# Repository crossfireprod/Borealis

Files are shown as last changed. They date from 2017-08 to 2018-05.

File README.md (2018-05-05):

Borealis
==================

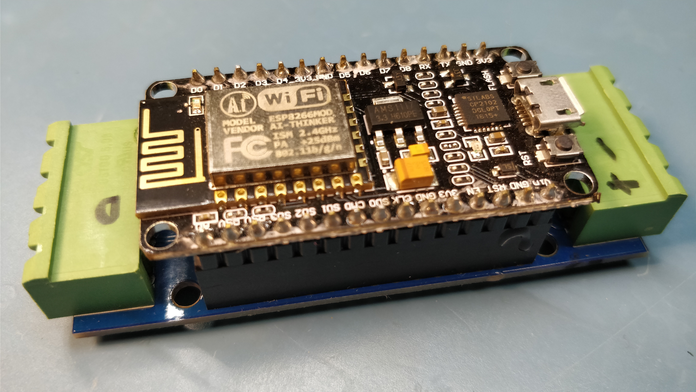
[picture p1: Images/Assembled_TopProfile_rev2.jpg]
Borealis Assembled - Top Profile
  

WS2812/DMX Light Controller For the [ESPixelStick Firmware](https://github.com/forkineye/ESPixelStick) by Shelby Merrick (forkineye).  Hardware supports both DMX (RS-485) and Pixel (WS2811/WS2812) output modes.

**Key Features**
* The [NodeMCU](https://en.wikipedia.org/wiki/NodeMCU) DEVKIT 1.0 was chosen due to pricepoint, availability, form factor, and onboard 3.3v power supply / USB interface (programmer).  
* Either a DC barrel jack or 5.08mm pluggable terminals may be used to supply power.  
* Output power and data is provided via 5.08mm pluggable terminal blocks.  
* PTC is used in lieu of a traditional fuse.  
* Drill hole in PCB allows for use of reverse firing activity LED, if desired.

Bill Of Materials
-------------------

A Bill Of Materials detailing the specific parts used in our most recent production run can be found on Octopart.  Pricing is more or less optimized around single unit quanties.

* [Pixel (WS2811/WS2812) Version](https://octopart.com/bom-tool/HFxE4Ql2)
* [DMX (RS-485) Version](https://octopart.com/bom-tool/G0dtO20q)

Note: If desired, boards can be populated for both DMX and Pixel use.  (Output mode defined by firmware configuration.)

Repository Contents
-------------------

* **/Hardware** - Eagle Schematic & PCB Layout
* **/Software** - [Platformio](http://platformio.org/) project containing [ESPixelStick Firmware](https://github.com/forkineye/ESPixelStick).
* **/Images** - Images of the schematic / PCB design, as well as a fully assembled unit.

License
-------------------

All contents of this repository are released under [Creative Commons Share-alike 4.0](http://creativecommons.org/licenses/by-sa/4.0/).

Design By: Greg Pohodich & [*ZachCross.com*](https://ZachCross.com)

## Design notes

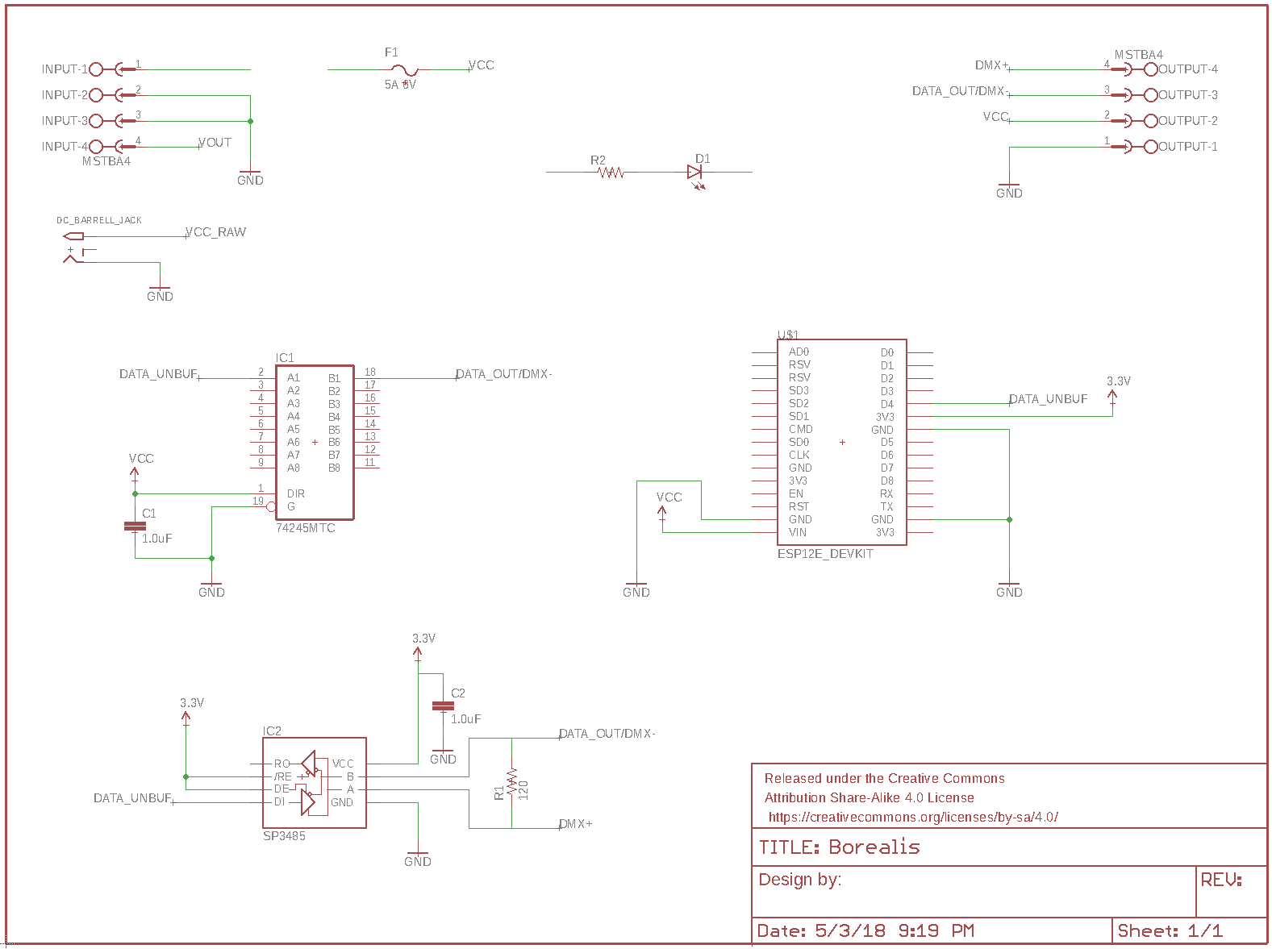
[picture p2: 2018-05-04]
Images/Schematic_Borealis_DMX&Pixel.png

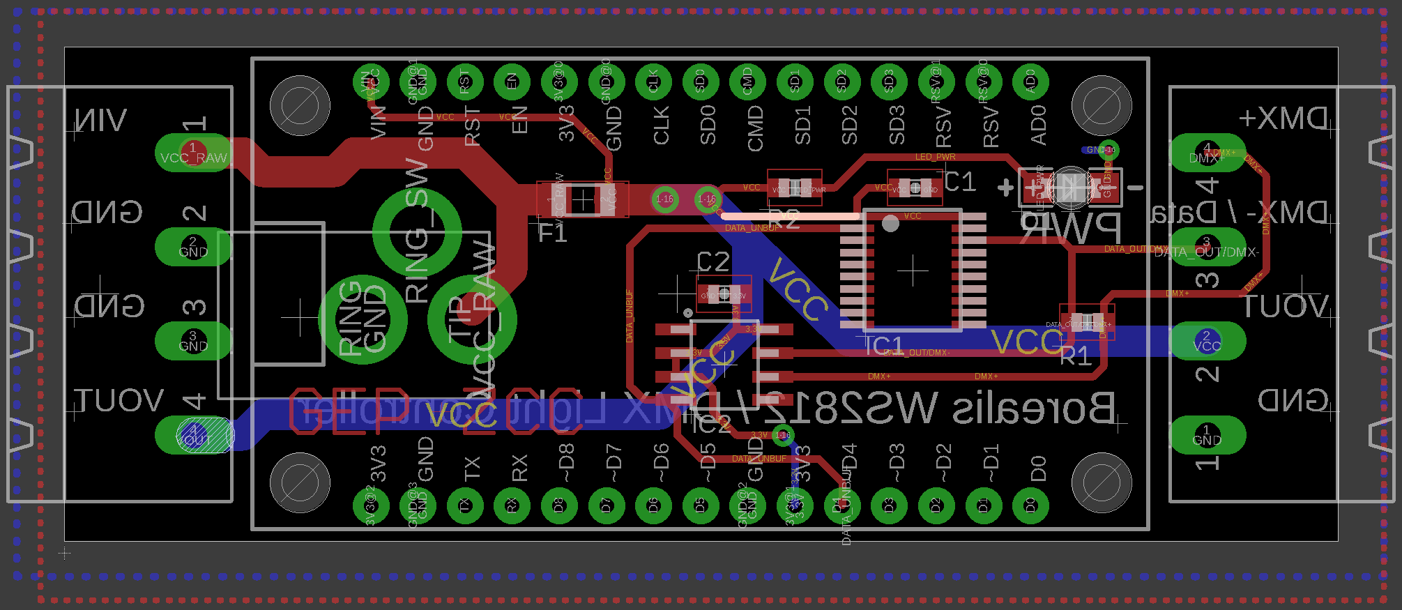
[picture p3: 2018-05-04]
Images/PCBLayout_Borealis_DMX&Pixel.png

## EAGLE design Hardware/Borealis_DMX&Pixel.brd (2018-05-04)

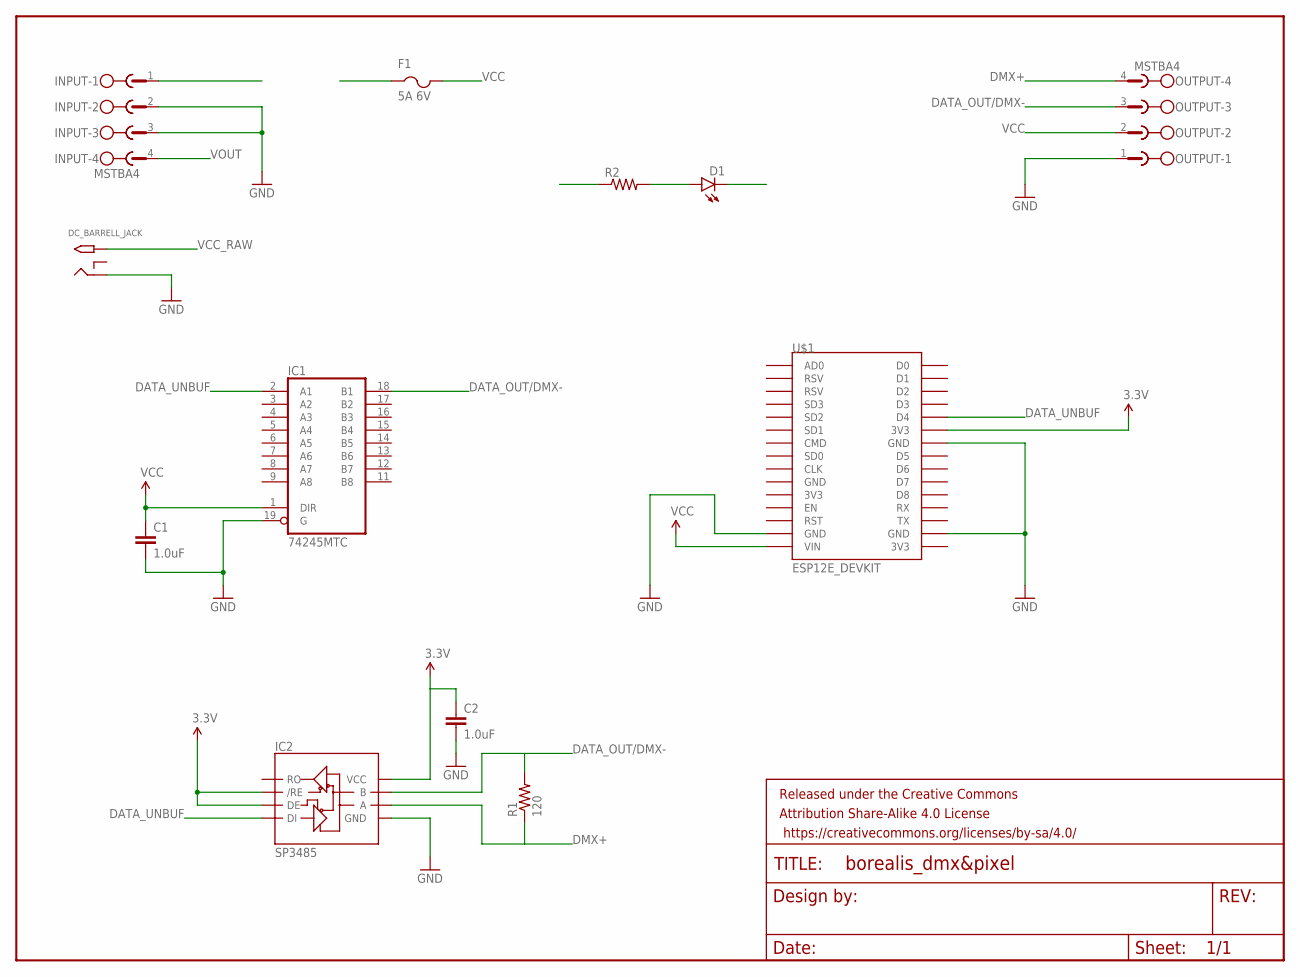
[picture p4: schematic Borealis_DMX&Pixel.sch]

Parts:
C1, C2: 1.0uF; 0603-CAP
D1: LED1206-BOTTOM; LED-1206-BOTTOM
DC_BARRELL_JACK: 2.1MMJACKTHM; PJ-102A
F1: 5A 6V; R1206
FRAME1: FRAME-LETTERNO_PACKAGE; DUMMY
IC1: 74245MTC; SSOP20
IC2: SP3485; SO08
INPUT: MSTBA4
OUTPUT: MSTBA4
R1: 120; 0603-RES
R2: RESISTOR0603-RES; 0603-RES
U$1: ESP12E_DEVKIT; DEV_LAYOUT

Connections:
3.3V: C2.1, IC2.2 (/RE), IC2.3 (DE), IC2.8 (VCC), U$1.3V3@1 (3V3)
DATA_OUT/DMX-: IC1.18 (B1), IC2.7 (B), OUTPUT.3, R1.2
DATA_UNBUF: IC1.2 (A1), IC2.4 (DI), U$1.D4
DMX+: IC2.6 (A), OUTPUT.4, R1.1
GND: C1.2, C2.2, D1.C, DC_BARRELL_JACK.RING, IC1.10 (GND), IC1.19 (G), IC2.5 (GND), INPUT.2, INPUT.3, OUTPUT.1, U$1.GND@1 (GND), U$1.GND@2 (GND), U$1.GND@3 (GND)
LED_PWR: D1.A, R2.2
VCC: C1.1, F1.2, IC1.1 (DIR), IC1.20 (VCC), OUTPUT.2, R2.1, U$1.VIN
VCC_RAW: DC_BARRELL_JACK.TIP, F1.1, INPUT.1
VOUT: INPUT.4

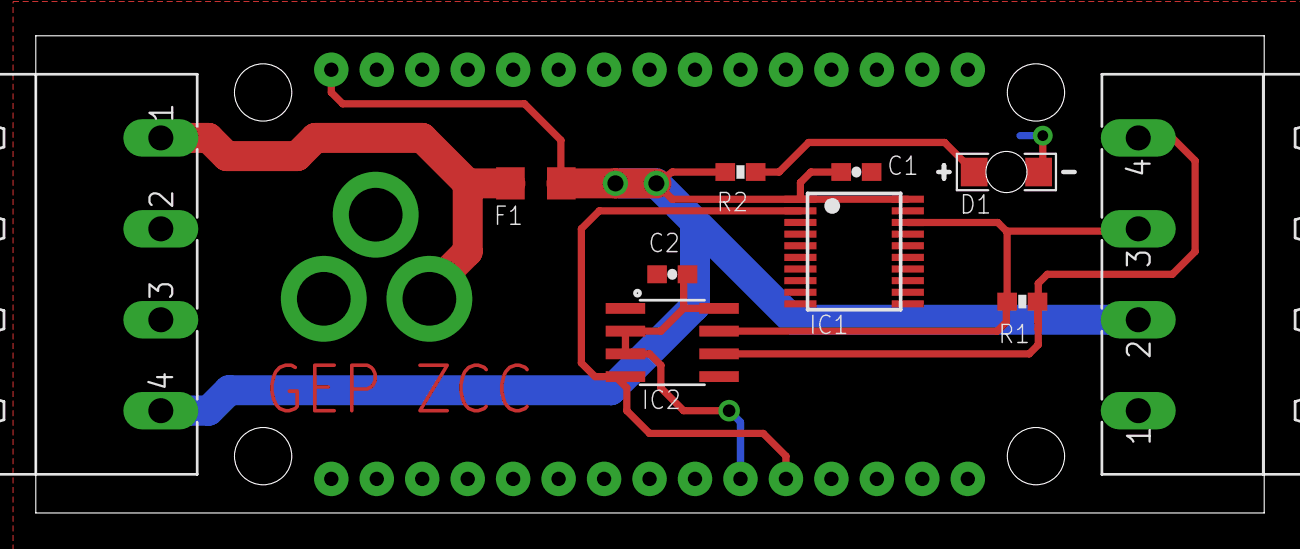
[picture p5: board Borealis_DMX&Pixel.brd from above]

Board: 2 copper layers, 68.6 x 26.7 mm, 13 parts (1 on the bottom side), 8 nets.

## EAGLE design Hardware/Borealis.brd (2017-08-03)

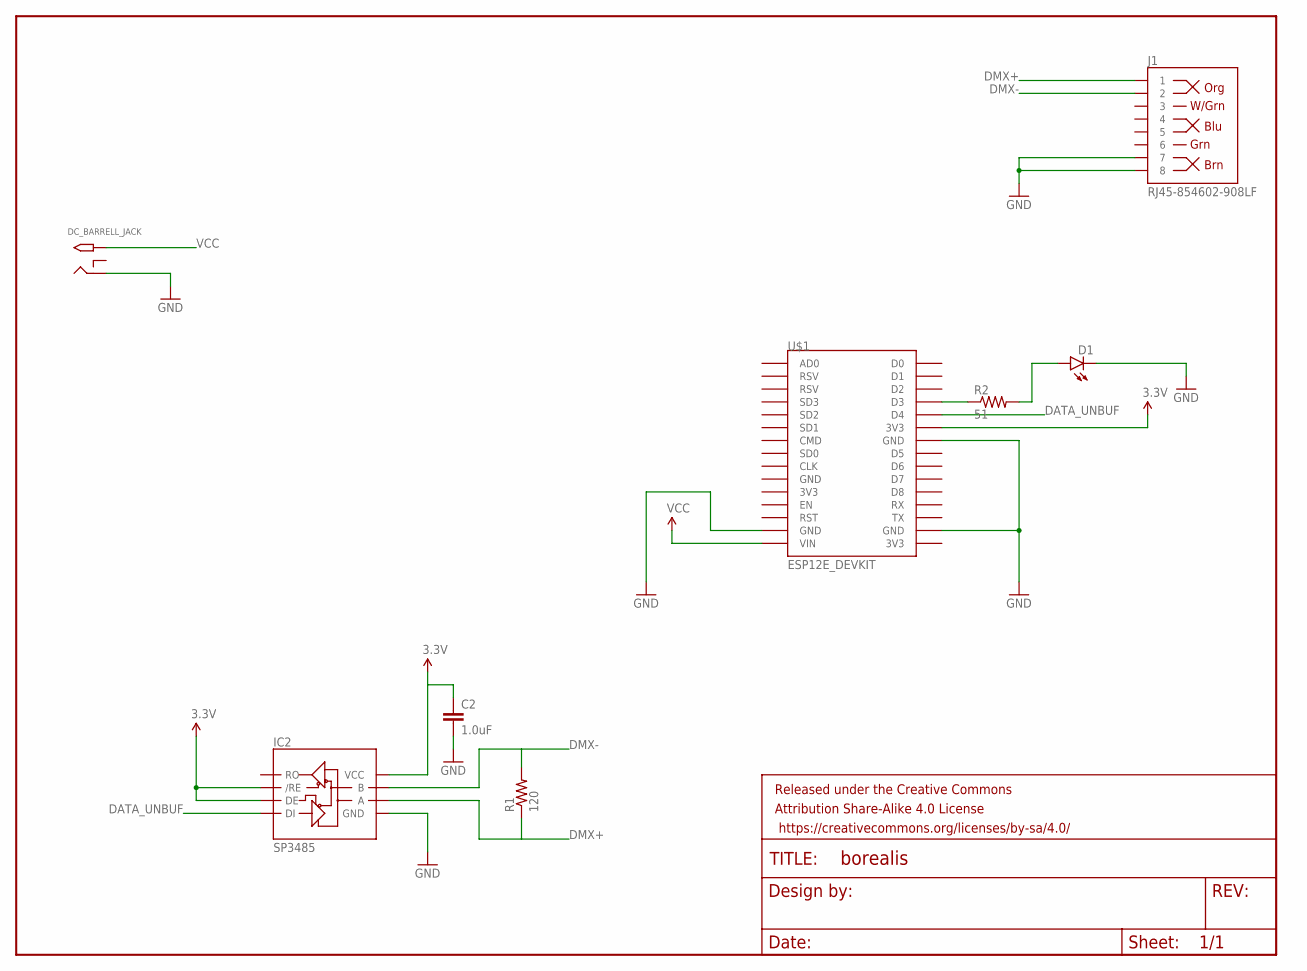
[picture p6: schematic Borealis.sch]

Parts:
C2: 1.0uF; 0603-CAP
D1: LED1206-BOTTOM; LED-1206-BOTTOM
DC_BARRELL_JACK: 2.1MMJACKTHM; PJ-102A
FRAME1: FRAME-LETTERNO_PACKAGE; DUMMY
IC2: SP3485; SO08
J1: RJ45-854602-908LF; RJ45-GREG
R1: 120; 0603-RES
R2: 51; 0603-RES
U$1: ESP12E_DEVKIT; DEV_LAYOUT

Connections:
3.3V: C2.1, IC2.2 (/RE), IC2.3 (DE), IC2.8 (VCC), U$1.3V3@1 (3V3)
DATA_UNBUF: IC2.4 (DI), U$1.D4
DMX+: IC2.6 (A), J1.1, R1.1
DMX-: IC2.7 (B), J1.2, R1.2
GND: C2.2, D1.C, DC_BARRELL_JACK.RING, IC2.5 (GND), J1.7, J1.8, U$1.GND@1 (GND), U$1.GND@2 (GND), U$1.GND@3 (GND)
LED_PWR: D1.A, R2.2
unnamed: R2.1, U$1.D3
VCC: DC_BARRELL_JACK.TIP, U$1.VIN

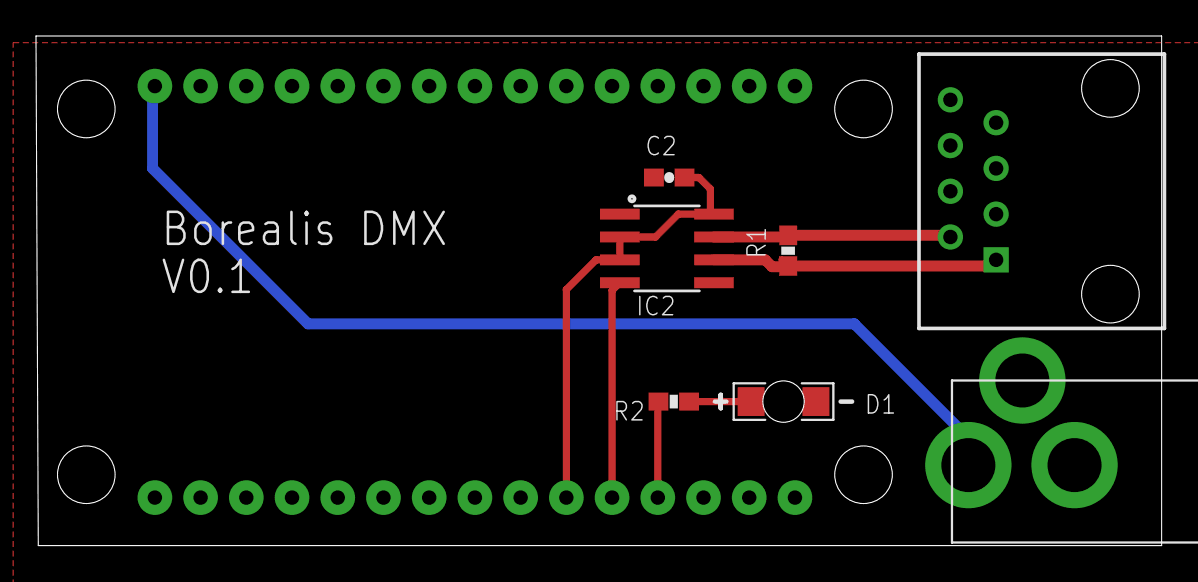
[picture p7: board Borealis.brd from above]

Board: 2 copper layers, 62.5 x 28.3 mm, 9 parts (0 on the bottom side), 8 nets.

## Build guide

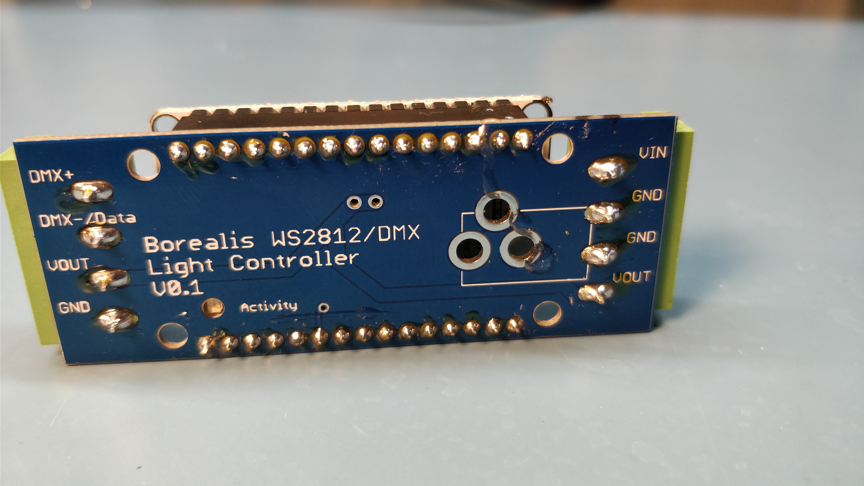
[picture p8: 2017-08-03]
Images/Assembled_Back.jpg

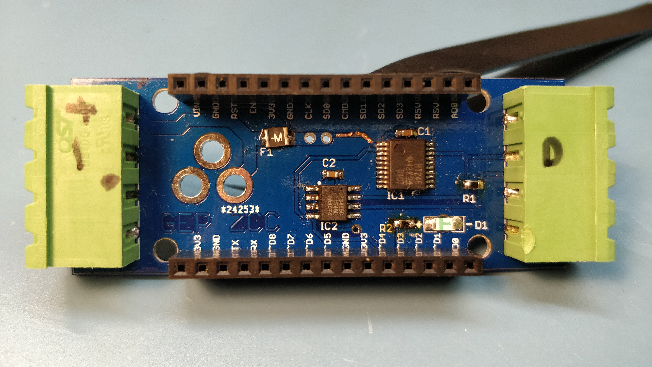
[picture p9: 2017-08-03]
Images/Assembled_Front.jpg

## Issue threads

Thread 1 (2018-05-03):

Can you post Pixel schematic ?

vziukas, 2018-05-03:
Hi, great idea.

I see schematic for DMX version. Can you post or explain how to connect in pixel mode? Will it work with ESPixelStick firmware ?

Thanks !

crossfireprod, 2018-05-03:
@vziukas - Good catch, looking back it appears that I've posted schematic / PCB layout screenshots from an earlier design.  I'll have to poke around a bit, but I expect to have updates committed by the end of the week.  In any case, yes, the ESPixelStick FW can be used for either DMX or "pixel" output.

vziukas, 2018-05-03:
@crossfireprod thanks! Looking forward to see updated version.

crossfireprod, 2018-05-04:
@vziukas - Updated (proper) design files have been committed.  Thanks again for the catch!  (After the initial design, @Ulto put together a DMX only version that I inadvertently included instead when initially creating this repository.)

Now that we've got the right design files, take a look at the schematic and you'll see the DATA_OUT/DMX- net is where the WS2812 pixels will get their data stream from.
https://raw.githubusercontent.com/crossfireprod/Borealis/master/Images/Schematic_Borealis_DMX%26Pixel.png

If you don't have any desire to make use of the DMX output functionality, feel free not to populate IC2, C2, and R1.

Hope this helps, let me us (@Ulto and I) know how you make out!

Closed 2018-05-04.

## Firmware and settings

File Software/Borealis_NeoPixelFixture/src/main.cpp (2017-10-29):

/* === INCLUDES === */
  // OTA Update
  #include <ESP8266WiFi.h>
  #include <ESP8266mDNS.h>
  #include <WiFiUdp.h>
  #include <ArduinoOTA.h>

  // WS2812
  #include <WS2812FX.h>

  // aREST
  #include <aREST.h>
  #include <PubSubClient.h> // cloud

/* === DEFINITIONS === */
  // OTA Update
  const char* ssid      = "";
  const char* password  = "";
  #define     HOSTNAME  "ESP_"

  // WS2812
  #define LED_COUNT   108
  #define LED_PIN     2

  WS2812FX ws2812fx = WS2812FX(LED_COUNT, LED_PIN, NEO_GRB + NEO_KHZ400);

  // aREST
  aREST rest = aREST();

  #define LISTEN_PORT           80
  WiFiServer server(LISTEN_PORT);

  // Function Prototypes
  int start(String);
  int stop(String);
  int setMode(String);
  int setSpeed(String);
  int setColor(String);
  int setBrightness(String);

  int isRunning(String);
  int getModeCount(String);

  int restart(String);


void setup() {
  // UART - Debug Messages
  Serial.begin(115200);
  Serial.println("Booting");

  // WiFi
  WiFi.mode(WIFI_STA);
  WiFi.begin(ssid, password);
  while (WiFi.waitForConnectResult() != WL_CONNECTED) {
    Serial.println("Connection Failed! Rebooting...");
    delay(5000);
    ESP.restart();
  }

  // OTA
  // Port defaults to 8266
  // ArduinoOTA.setPort(8266);

  // Hostname defaults to esp8266-[ChipID]
  //ArduinoOTA.setHostname(HOSTNAME);

  // No authentication by default
  //ArduinoOTA.setPassword("password");

  // Password can be set with it's md5 value as well
  // MD5(admin) = 21232f297a57a5a743894a0e4a801fc3
  // ArduinoOTA.setPasswordHash("21232f297a57a5a743894a0e4a801fc3");

  ArduinoOTA.onStart([]() {
    String type;
    if (ArduinoOTA.getCommand() == U_FLASH)
      type = "sketch";
    else // U_SPIFFS
      type = "filesystem";

    // NOTE: if updating SPIFFS this would be the place to unmount SPIFFS using SPIFFS.end()
    Serial.println("Start updating " + type);

    // Clean Exit?
    ws2812fx.stop();

  });
  ArduinoOTA.onEnd([]() {
    Serial.println("\nEnd");
  });
  ArduinoOTA.onProgress([](unsigned int progress, unsigned int total) {
    Serial.printf("Progress: %u%%\r", (progress / (total / 100)));
  });
  ArduinoOTA.onError([](ota_error_t error) {
    Serial.printf("Error[%u]: ", error);
    if (error == OTA_AUTH_ERROR) Serial.println("Auth Failed");
    else if (error == OTA_BEGIN_ERROR) Serial.println("Begin Failed");
    else if (error == OTA_CONNECT_ERROR) Serial.println("Connect Failed");
    else if (error == OTA_RECEIVE_ERROR) Serial.println("Receive Failed");
    else if (error == OTA_END_ERROR) Serial.println("End Failed");
  });
  ArduinoOTA.begin();
  Serial.println("Ready");
  Serial.print("IP address: ");
  Serial.println(WiFi.localIP());

  // WS2812
  ws2812fx.init();
  ws2812fx.start();
  ws2812fx.setMode(FX_MODE_STATIC);

  // aREST
    // Functions to be exposed
    rest.function("start", start);
    rest.function("stop", stop);
    rest.function("setMode", setMode);
    rest.function("setSpeed", setSpeed);
    rest.function("setColor", setColor);
    rest.function("setBrightness", setBrightness);
    rest.function("isRunning", isRunning);
    rest.function("getModeCount", getModeCount);

    rest.function("restart", restart);

    // Give name & ID to the device (ID should be 6 characters long)
    rest.set_id("1");
    rest.set_name("esp8266");

    // Start the server
    server.begin();
    Serial.println("Server Started");

  }


void loop() {
  // OTA
  ArduinoOTA.handle();

  // WS2812FX
  ws2812fx.service();

  // aREST
  WiFiClient client = server.available();
  if (!client) {
    return;
  }
  while(!client.available()){
    delay(1);
  }
  rest.handle(client);

  // Connect to the cloud
  rest.handle(client);
}


int start(String) {
  ws2812fx.start();

  return 1;
}


int stop(String) {
  ws2812fx.stop();

  return 1;
}


int setMode(String command) {
  int mode = command.toInt();

  ws2812fx.setMode(mode);

  return mode;
}


int setSpeed(String command) {
  int speed = command.toInt();

  ws2812fx.setSpeed(speed);

  return speed;
}


int setColor(String command) {
  int color = command.toInt();

  ws2812fx.setColor(color);

  return 1;
}


int setBrightness(String command) {
  int brightness = command.toInt();

  ws2812fx.setBrightness(brightness);

  return brightness;
}


int isRunning(String) {
  return ws2812fx.isRunning();
}


int getModeCount(String) {
  return ws2812fx.getModeCount();
}

int restart(String) {
  ws2812fx.stop();
  ESP.restart();

  return 1;
}

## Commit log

2017-08-03 Initial commit of design files, images, and README.
    [Borealis - DMX.brd]
2017-08-03 Updated top profile image.
    [Borealis - DMX.sch]
2017-08-03 Updating file names.
    [Borealis - DMX.sch, Borealis.brd]
2017-08-03 Added Borealis Schematic
    Also sample images added
    [Borealis.sch]
2018-05-04 Replaced erroneously committed DMX only output design files with DMX & Pixel version refrenced in repo documentation.
    [Borealis_DMX&Pixel.brd, Borealis_DMX&Pixel.sch]

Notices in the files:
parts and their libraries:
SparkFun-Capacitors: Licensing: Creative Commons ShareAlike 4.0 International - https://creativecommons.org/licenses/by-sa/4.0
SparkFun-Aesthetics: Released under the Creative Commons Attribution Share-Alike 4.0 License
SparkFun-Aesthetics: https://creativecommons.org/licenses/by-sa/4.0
